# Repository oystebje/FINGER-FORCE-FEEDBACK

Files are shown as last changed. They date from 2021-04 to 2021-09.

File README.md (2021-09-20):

# FINGER-FORCE-FEEDBACK

Repository for project on reality-based modelling of partial meniscectomy.

Repository contains code and CAD models for:
1) Prototype for collecting force-position data from Acufect Upbiter Punch, with ARDUINO MKR Zero based FSR-sensor and potentiometer.
2) Protype for rendering haptic feedback of partial meniscectomy using self-designed hardware, Arduino DUE with SimpleFOC shield, BLDC motor, and AMT 102V encoder.

Prototype for collecting data:


Prototype for haptic rendering:




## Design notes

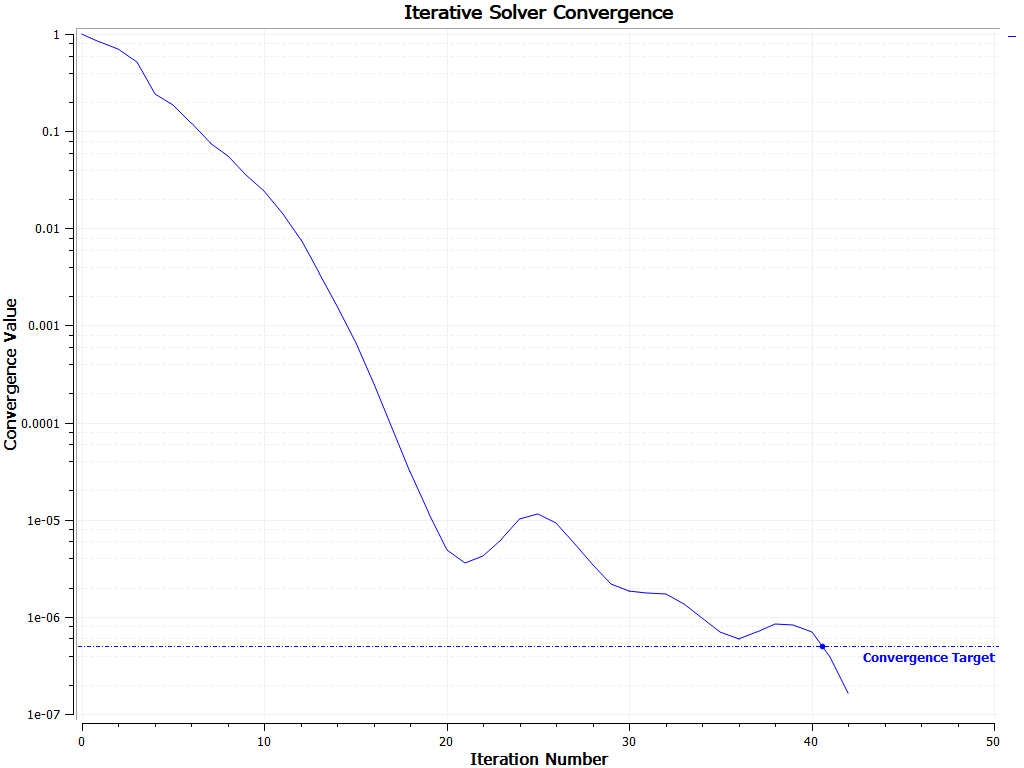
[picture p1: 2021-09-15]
1_Prototype_for_data_collection/CAD/Hand_Held_Devices_Concept/Iterative Solver Convergence.png

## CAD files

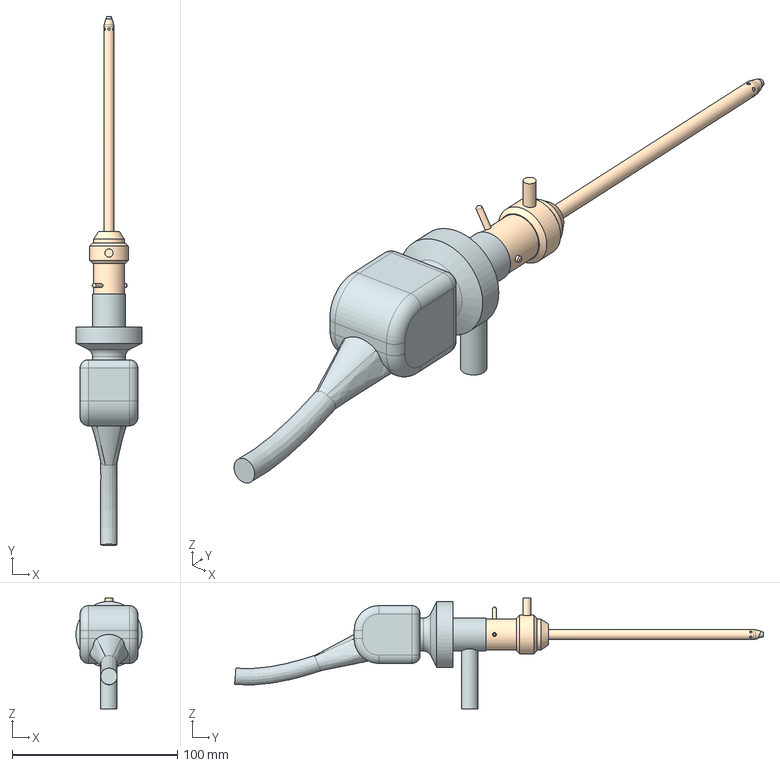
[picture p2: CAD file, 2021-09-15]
1_Prototype_for_data_collection/CAD/Hand_Held_Devices_Concept/STP/SCOPE_ASSEMBLY.stp
40.0 x 320.5 x 67.0 mm
INTRODUCER_SLEEVE
SCOPE_DUMMY

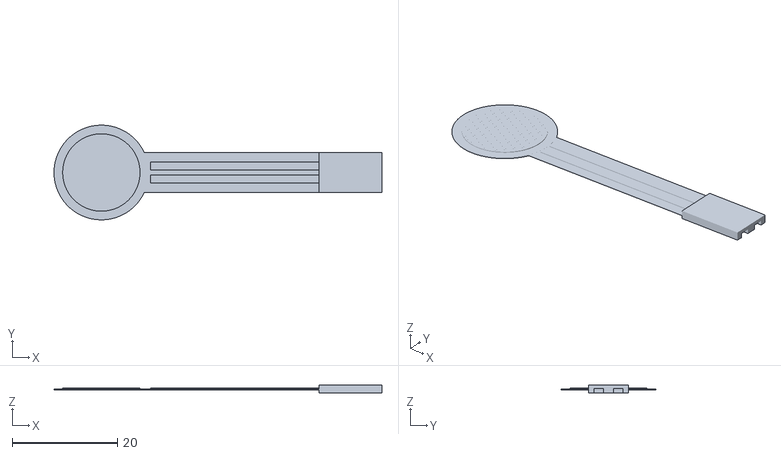
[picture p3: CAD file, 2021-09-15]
1_Prototype_for_data_collection/CAD/3D-print/FSR07CE.stl
62.3 x 18.0 x 1.50

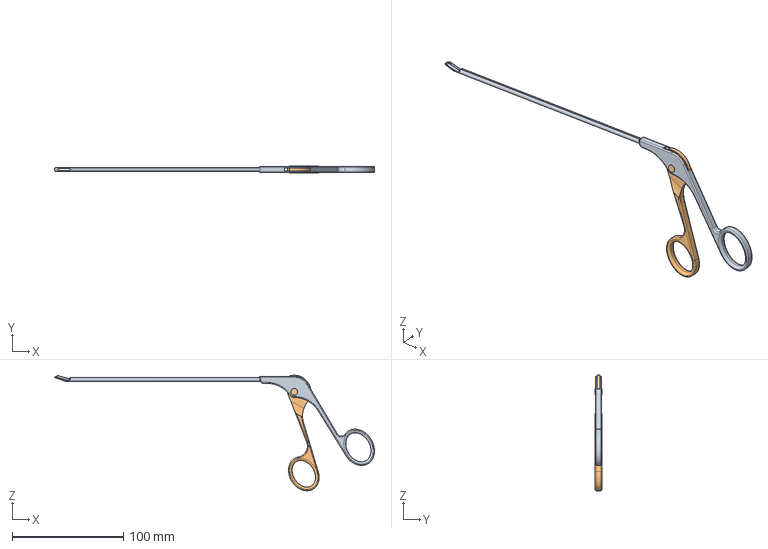
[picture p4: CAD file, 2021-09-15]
1_Prototype_for_data_collection/CAD/Hand_Held_Devices_Concept/STP/ACUFEX_1_5mm_UPBITER_PUNCH_7207735.stp
287.8 x 6.00 x 103.9 mm
ACUFEX_PUNCH_MAIN_BODY
ACUFEX_TRIGGER

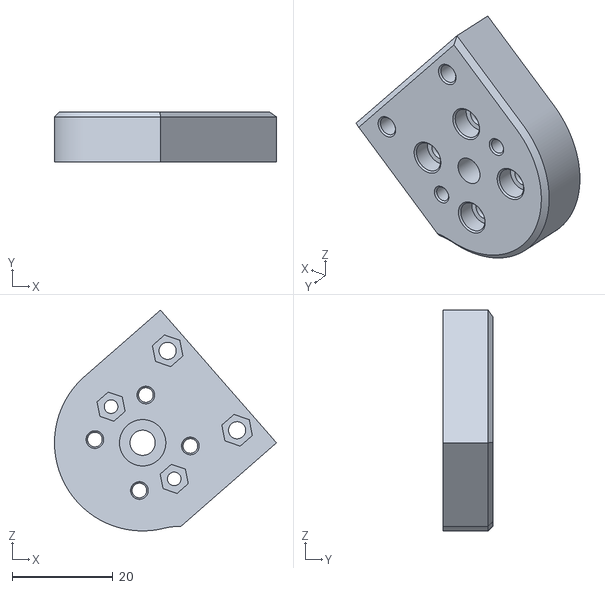
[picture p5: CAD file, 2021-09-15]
2_Prototype_for_haptic_rendering/CAD/3D-PRINT/THUMB_KNOB_REVC_1.stl
44.1 x 10.0 x 43.8

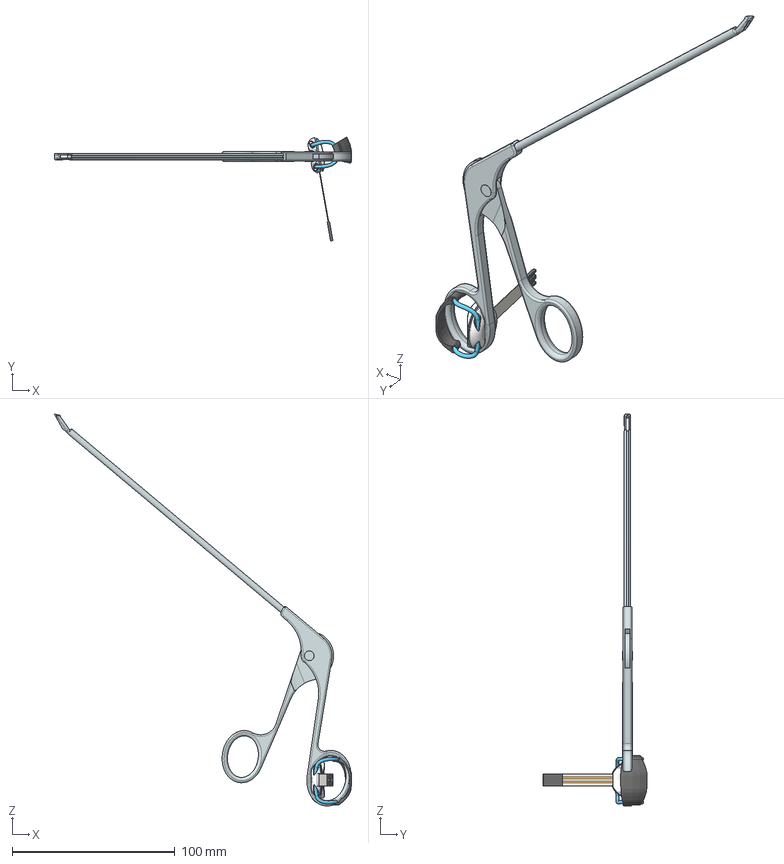
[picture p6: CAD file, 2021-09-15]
1_Prototype_for_data_collection/CAD/Hand_Held_Devices_Concept/STP/FINGER_DEVICE_CONCEPT_1.stp
182.8 x 64.0 x 240.9 mm
FSR07CE
FSR07_thumb_adapter
FSR07_THUMB_ADAPTER_TOP
Rope_attachment
Strap
hand_import
ACUFEX_PUNCH_MAIN_BODY
ACUFEX_TRIGGER

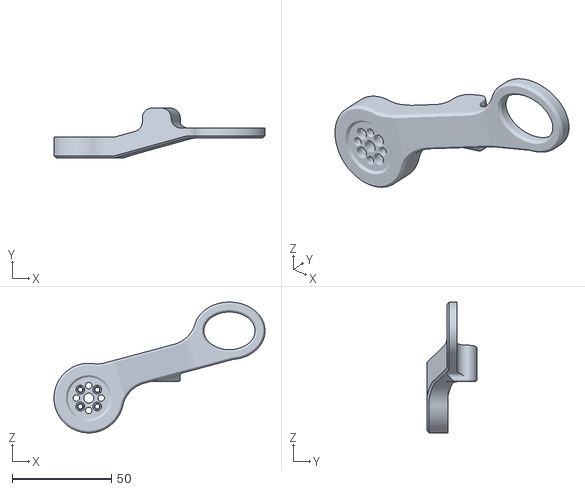
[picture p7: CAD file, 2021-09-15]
2_Prototype_for_haptic_rendering/CAD/3D-PRINT/FINGER_HANDLE_REVD.stl
106.1 x 25.0 x 65.7

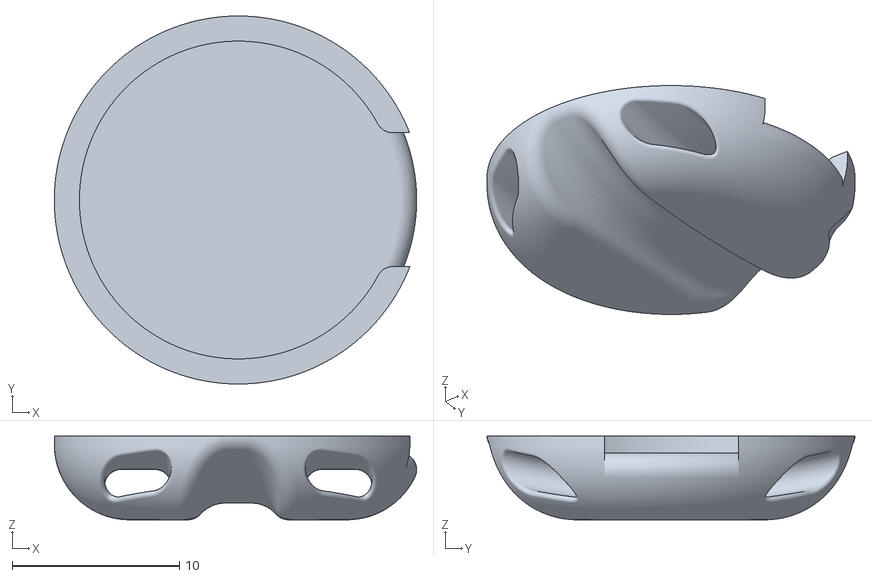
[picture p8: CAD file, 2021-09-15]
1_Prototype_for_data_collection/CAD/3D-print/FSR07_thumb_adapter.stl
21.7 x 22.0 x 5.00

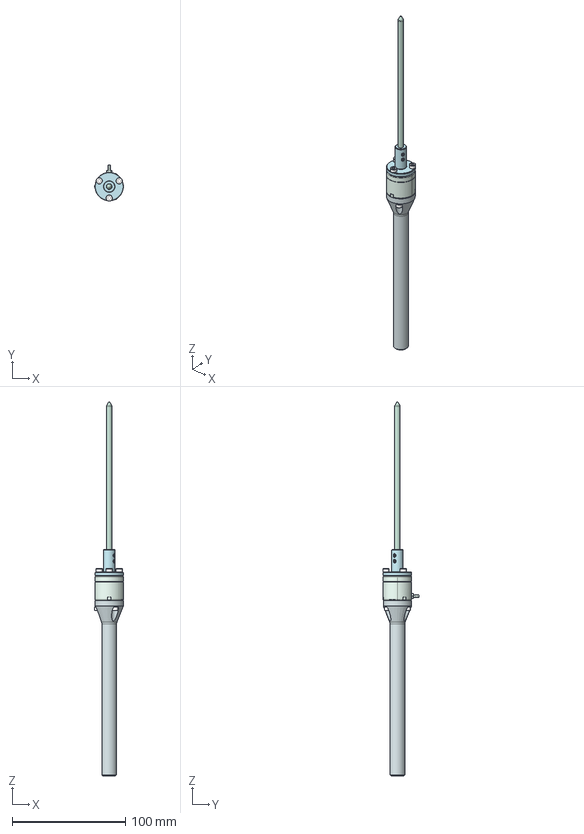
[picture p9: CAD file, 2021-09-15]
1_Prototype_for_data_collection/CAD/Hand_Held_Devices_Concept/STP/Hand_held_concept2_01022021.stp
25.4 x 32.2 x 330.2 mm
ATI-9105-TW-NANO25-R
CONCEPT2_ADAPTER
Dilatator
CONCEPT2_HANDLE
bolt_din912_m3x12 x 6
SET_SCREW_DIN914_M3x4 x 2

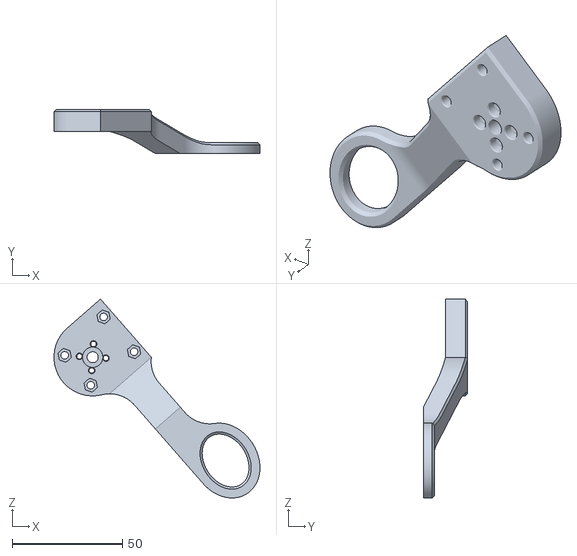
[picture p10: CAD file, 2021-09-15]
2_Prototype_for_haptic_rendering/CAD/3D-PRINT/THUMB_HANDLE.stl
93.3 x 20.0 x 90.0

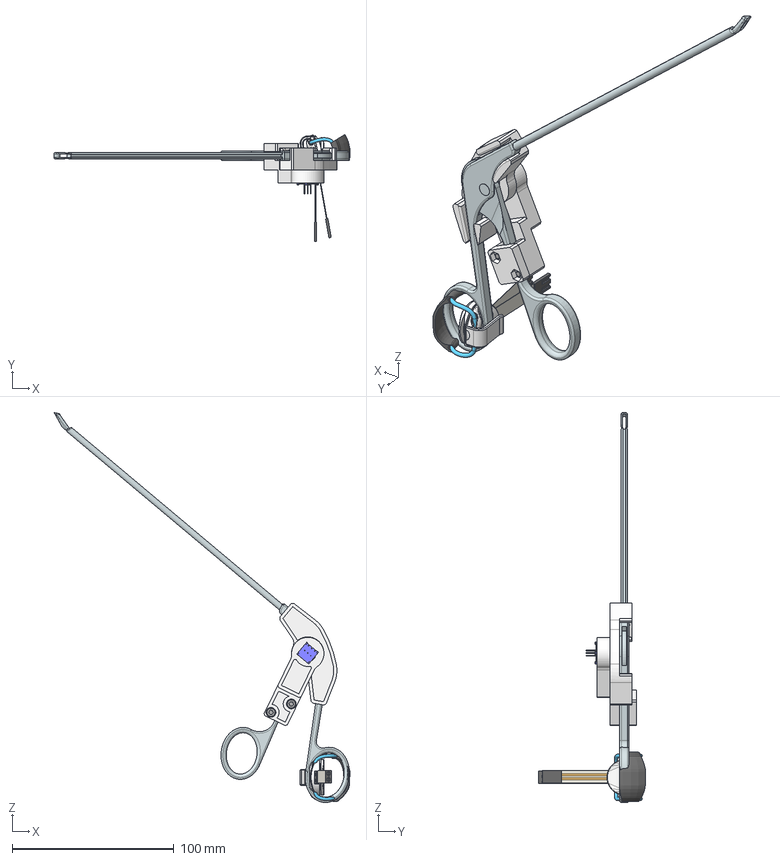
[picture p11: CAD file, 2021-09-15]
1_Prototype_for_data_collection/CAD/Hand_Held_Devices_Concept/STP/FINGER_DEVICE_CONCEPT_1_27052021.stp
182.8 x 66.2 x 240.9 mm
FSR07CE x 2
FSR07_thumb_adapter
FSR07_THUMB_ADAPTER_TOP
Rope_attachment
Strap
hand_import
ACUFEX_PUNCH_MAIN_BODY
ACUFEX_TRIGGER
COM-09806_Potentiometer x 2
POTMETER_FRAME_1
POTMETER_FRAME_2
bolt_din912_m3x12 x 2
POTMETER_FRAME_3
FSR_BASE
FSR_TOP

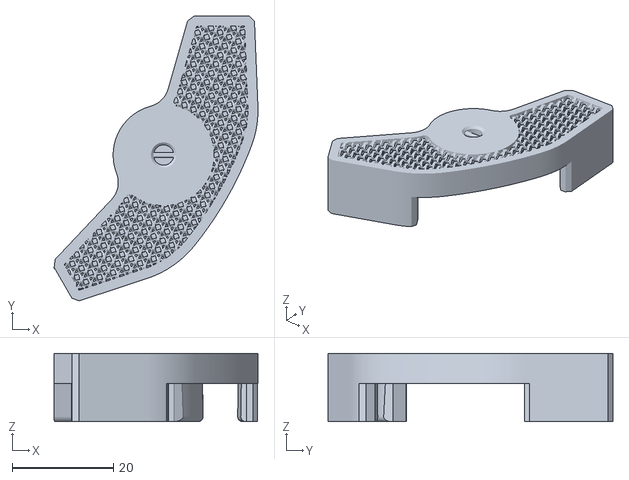
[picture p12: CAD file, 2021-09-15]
1_Prototype_for_data_collection/CAD/3D-print/POTMETER_FRAME_1_RevC.stl
40.4 x 56.4 x 13.5

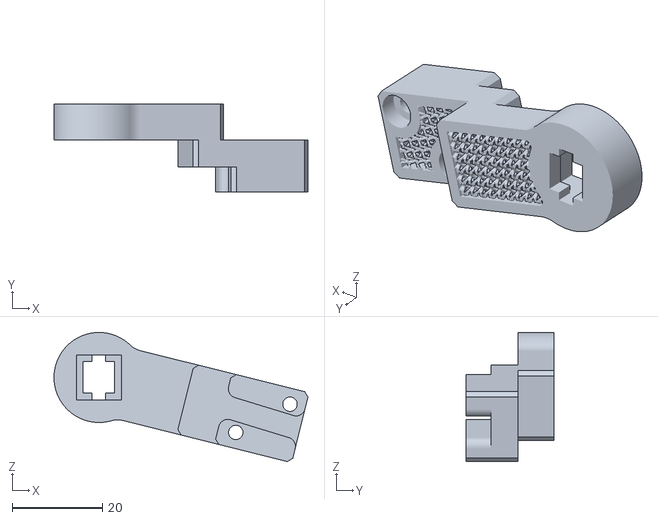
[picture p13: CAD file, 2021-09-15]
1_Prototype_for_data_collection/CAD/3D-print/POTMETER_FRAME_2_RevC.stl
56.4 x 19.5 x 28.7

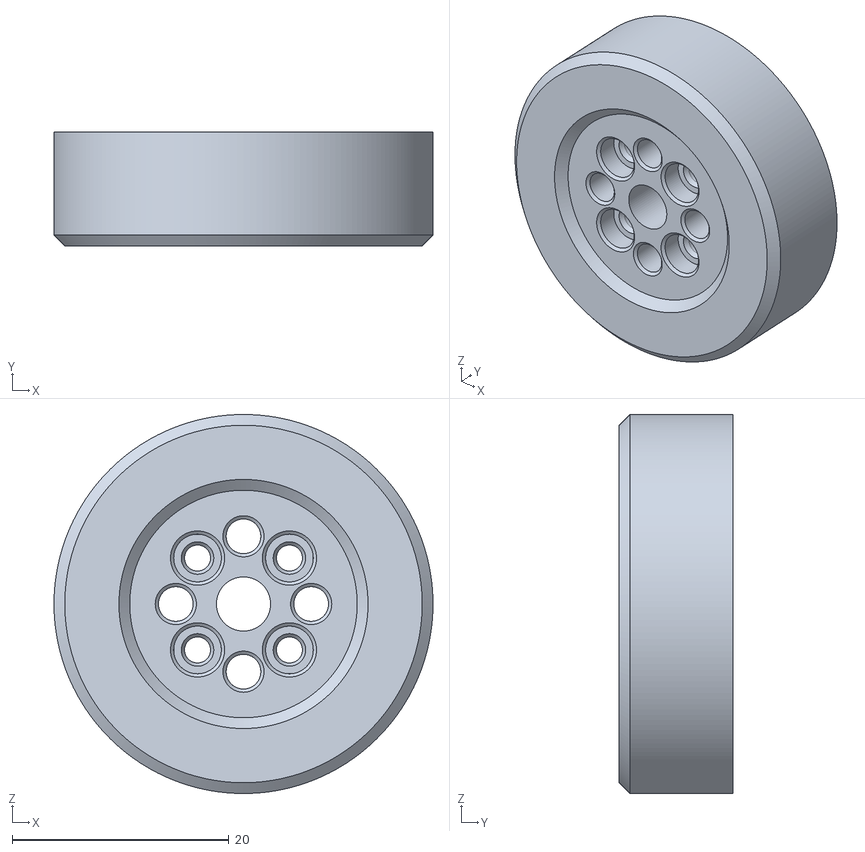
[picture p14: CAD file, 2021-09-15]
2_Prototype_for_haptic_rendering/CAD/3D-PRINT/FINGER_KNOB_REVC_1.stl
35.0 x 10.5 x 35.0

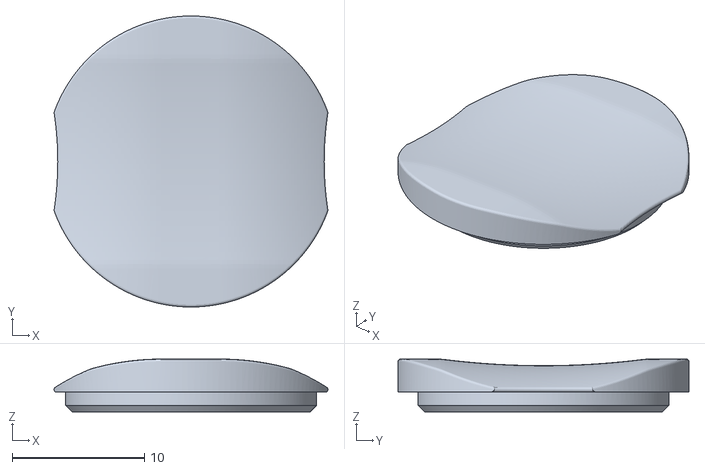
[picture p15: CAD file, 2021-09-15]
1_Prototype_for_data_collection/CAD/3D-print/FSR07_THUMB_ADAPTER_TOP_RevB.stl
20.7 x 22.0 x 4.00

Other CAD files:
1_Prototype_for_data_collection/CAD/3D-print/FSR07_thumb_adapter_RevB.stl
2_Prototype_for_haptic_rendering/CAD/3D-PRINT/CONCEPT2_HANDLE.stl
1_Prototype_for_data_collection/CAD/3D-print/POTMETER_FRAME_3.stl
2_Prototype_for_haptic_rendering/CAD/3D-PRINT/TOOL_ADAPTER.stl
1_Prototype_for_data_collection/CAD/3D-print/FSR_BASE_RevA.stl
1_Prototype_for_data_collection/CAD/3D-print/FSR_TOP.stl
1_Prototype_for_data_collection/CAD/3D-print/POTMETER_FRAME_1.stl
1_Prototype_for_data_collection/CAD/3D-print/POTMETER_FRAME_1_RevB.stl
1_Prototype_for_data_collection/CAD/3D-print/POTMETER_FRAME_2.stl
1_Prototype_for_data_collection/CAD/3D-print/POTMETER_FRAME_2_RevB.stl
1_Prototype_for_data_collection/CAD/BACKUPS/Hand_Held_Devices_Concept/ACUFEX_1_5mm_UPBITER_PUNCH_7207735.prt
1_Prototype_for_data_collection/CAD/BACKUPS/Hand_Held_Devices_Concept/ACUFEX_PUNCH_MAIN_BODY.prt
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

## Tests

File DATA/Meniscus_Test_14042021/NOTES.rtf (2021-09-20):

NOTES:

PART I: Samples with tape covering FSR sensor. Idea was to get better force distribution over FSR, but ended up biasing measures (force not being zero unloaded)

PART II: Tape was removed. Zero force on zero load, but pay attention to force behavior.

No cut through for the following tests:
- Pattellar ligament fast&slow
- Skin knee lateral fast&slow
- Muscle posterior

Mostly cut through for meniscus tests. Perhaps less frequent for later ones (PART II).

Some hysteresis from previous cutting on later tests.

MUSCLE POSTERIOR:
Difficult to tell whether cut through or not. Generally very little resistance (stiffness).

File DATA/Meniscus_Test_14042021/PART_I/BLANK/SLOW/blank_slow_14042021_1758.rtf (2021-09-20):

Please move the lever to the outermost position and hold for 5 seconds
Outermost position recorded
Please move the lever to the innermost position and hold for 5 seconds
Innermost position recorded
Potentiometer calibration completed
FSR reading, FSR Force [N], angle [deg], time [ms]
1 0.73 486.00 9.23 30003.00
1 0.73 486.00 9.23 30005.00
0 0.00 486.00 9.23 30008.00
0 0.00 485.00 8.97 30010.00
1 0.73 486.00 9.23 30013.00
1 0.73 485.00 8.97 30016.00
0 0.00 486.00 9.23 30018.00
1 0.73 487.00 9.48 30021.00
0 0.00 486.00 9.23 30024.00
1 0.73 486.00 9.23 30026.00
1 0.73 486.00 9.23 30029.00
0 0.00 486.00 9.23 30031.00
1 0.73 485.00 8.97 30034.00
1 0.73 487.00 9.48 30037.00
1 0.73 486.00 9.23 30039.00
0 0.00 486.00 9.23 30042.00
0 0.00 485.00 8.97 30045.00
0 0.00 486.00 9.23 30047.00
0 0.00 487.00 9.48 30050.00
1 0.73 486.00 9.23 30052.00
0 0.00 486.00 9.23 30055.00
0 0.00 487.00 9.48 30058.00
1 0.73 486.00 9.23 30060.00
1 0.73 486.00 9.23 30063.00
1 0.73 486.00 9.23 30066.00
1 0.73 486.00 9.23 30068.00
1 0.73 487.00 9.48 30071.00
0 0.00 485.00 8.97 30073.00
1 0.73 486.00 9.23 30076.00
0 0.00 486.00 9.23 30079.00
1 0.73 485.00 8.97 30081.00
1 0.73 486.00 9.23 30084.00
1 0.73 486.00 9.23 30087.00
0 0.00 486.00 9.23 30089.00
0 0.00 486.00 9.23 30092.00
0 0.00 485.00 8.97 30094.00
1 0.73 486.00 9.23 30097.00
1 0.73 486.00 9.23 30100.00
1 0.73 485.00 8.97 30102.00
1 0.73 485.00 8.97 30105.00
1 0.73 485.00 8.97 30107.00
1 0.73 486.00 9.23 30110.00
1 0.73 486.00 9.23 30113.00
1 0.73 486.00 9.23 30115.00
0 0.00 486.00 9.23 30118.00
0 0.00 486.00 9.23 30120.00
1 0.73 486.00 9.23 30123.00
1 0.73 486.00 9.23 30126.00
2 1.45 486.00 9.23 30129.00
0 0.00 485.00 8.97 30131.00
2 1.45 487.00 9.48 30134.00
1 0.73 486.00 9.23 30137.00
0 0.00 486.00 9.23 30139.00
1 0.73 485.00 8.97 30142.00
2 1.45 485.00 8.97 30145.00
1 0.73 486.00 9.23 30148.00
0 0.00 486.00 9.23 30150.00
1 0.73 486.00 9.23 30153.00
1 0.73 486.00 9.23 30155.00
1 0.73 486.00 9.23 30158.00
0 0.00 485.00 8.97 30161.00
1 0.73 485.00 8.97 30163.00
1 0.73 485.00 8.97 30166.00
1 0.73 486.00 9.23 30169.00
0 0.00 486.00 9.23 30171.00
0 0.00 486.00 9.23 30174.00
1 0.73 486.00 9.23 30176.00
0 0.00 487.00 9.48 30179.00
1 0.73 486.00 9.23 30182.00
1 0.73 487.00 9.48 30184.00
1 0.73 488.00 9.74 30187.00
1 0.73 487.00 9.48 30189.00
0 0.00 486.00 9.23 30192.00
1 0.73 487.00 9.48 30195.00
0 0.00 486.00 9.23 30197.00
2 1.45 485.00 8.97 30200.00
1 0.73 486.00 9.23 30203.00
0 0.00 487.00 9.48 30206.00
1 0.73 486.00 9.23 30208.00
1 0.73 487.00 9.48 30211.00
0 0.00 486.00 9.23 30213.00
1 0.73 486.00 9.23 30216.00
1 0.73 486.00 9.23 30219.00
1 0.73 486.00 9.23 30221.00
0 0.00 486.00 9.23 30224.00
0 0.00 487.00 9.48 30226.00
1 0.73 485.00 8.97 30229.00
0 0.00 486.00 9.23 30232.00
0 0.00 485.00 8.97 30234.00
0 0.00 486.00 9.23 30237.00
1 0.73 485.00 8.97 30239.00
1 0.73 486.00 9.23 30242.00
1 0.73 486.00 9.23 30245.00
1 0.73 486.00 9.23 30247.00
0 0.00 485.00 8.97 30250.00
2 1.45 486.00 9.23 30253.00
1 0.73 486.00 9.23 30256.00
1 0.73 485.00 8.97 30258.00
1 0.73 486.00 9.23 30261.00
1 0.73 485.00 8.97 30263.00
0 0.00 486.00 9.23 30266.00
1 0.73 486.00 9.23 30269.00
0 0.00 486.00 9.23 30271.00
0 0.00 485.00 8.97 30274.00
0 0.00 485.00 8.97 30276.00
1 0.73 485.00 8.97 30279.00
0 0.00 486.00 9.23 30282.00
1 0.73 486.00 9.23 30284.00
0 0.00 485.00 8.97 30287.00
0 0.00 487.00 9.48 30290.00
0 0.00 486.00 9.23 30292.00
1 0.73 486.00 9.23 30295.00
1 0.73 486.00 9.23 30298.00
0 0.00 486.00 9.23 30300.00
1 0.73 485.00 8.97 30303.00
2 1.45 486.00 9.23 30306.00
0 0.00 484.00 8.71 30308.00
0 0.00 486.00 9.23 30311.00
1 0.73 484.00 8.71 30314.00
0 0.00 484.00 8.71 30316.00
0 0.00 486.00 9.23 30319.00
1 0.73 486.00 9.23 30321.00
1 0.73 486.00 9.23 30324.00
0 0.00 485.00 8.97 30327.00
1 0.73 487.00 9.48 30329.00
1 0.73 487.00 9.48 30332.00
1 0.73 486.00 9.23 30334.00
1 0.73 486.00 9.23 30337.00
0 0.00 487.00 9.48 30340.00
0 0.00 486.00 9.23 30342.00
0 0.00 486.00 9.23 30345.00
1 0.73 486.00 9.23 30347.00
0 0.00 486.00 9.23 30350.00
0 0.00 486.00 9.23 30353.00
1 0.73 486.00 9.23 30355.00
0 0.00 486.00 9.23 30358.00
0 0.00 486.00 9.23 30360.00
0 0.00 487.00 9.48 30363.00
1 0.73 485.00 8.97 30366.00
1 0.73 486.00 9.23 30368.00
0 0.00 486.00 9.23 30371.00
1 0.73 486.00 9.23 30374.00
1 0.73 486.00 9.23 30376.00
1 0.73 486.00 9.23 30379.00
1 0.73 486.00 9.23 30381.00
0 0.00 486.00 9.23 30384.00
0 0.00 485.00 8.97 30387.00
5 3.62 486.00 9.23 30390.00
5 3.62 485.00 8.97 30393.00
7 5.07 485.00 8.97 30396.00
7 5.07 485.00 8.97 30399.00
15 10.83 486.00 9.23 30403.00
15 10.83 486.00 9.23 30406.00
16 11.54 487.00 9.48 30409.00
21 15.12 485.00 8.97 30412.00
20 14.40 486.00 9.23 30415.00
22 15.83 486.00 9.23 30419.00
22 15.83 485.00 8.97 30422.00
27 19.39 486.00 9.23 30425.00
32 22.94 485.00 8.97 30428.00
31 22.23 485.00 8.97 30431.00
32 22.94 486.00 9.23 30434.00
32 22.94 485.00 8.97 30437.00
33 23.65 486.00 9.23 30441.00
33 23.65 487.00 9.48 30444.00
32 22.94 486.00 9.23 30447.00
33 23.65 485.00 8.97 30450.00
32 22.94 486.00 9.23 30453.00
34 24.35 486.00 9.23 30456.00
31 22.23 485.00 8.97 30459.00
32 22.94 486.00 9.23 30462.00
33 23.65 486.00 9.23 30466.00
32 22.94 484.00 8.71 30469.00
35 25.06 484.00 8.71 30472.00
38 27.18 486.00 9.23 30475.00
36 25.76 485.00 8.97 30478.00
45 32.09 485.00 8.97 30482.00
44 31.39 485.00 8.97 30485.00
45 32.09 485.00 8.97 30488.00
47 33.50 486.00 9.23 30491.00
46 32.80 487.00 9.48 30495.00
46 32.80 486.00 9.23 30498.00
45 32.09 486.00 9.23 30501.00
45 32.09 485.00 8.97 30504.00
48 34.19 485.00 8.97 30507.00
48 34.19 486.00 9.23 30511.00
49 34.89 485.00 8.97 30514.00
48 34.19 485.00 8.97 30517.00
47 33.50 485.00 8.97 30520.00
48 34.19 485.00 8.97 30523.00
48 34.19 486.00 9.23 30526.00
49 34.89 487.00 9.48 30530.00
48 34.19 485.00 8.97 30533.00
50 35.59 485.00 8.97 30536.00
50 35.59 487.00 9.48 30539.00
49 34.89 486.00 9.23 30542.00
50 35.59 487.00 9.48 30546.00
49 34.89 486.00 9.23 30549.00
47 33.50 484.00 8.71 30552.00
46 32.80 486.00 9.23 30555.00
46 32.80 485.00 8.97 30558.00
46 32.80 486.00 9.23 30562.00
46 32.80 486.00 9.23 30565.00
44 31.39 485.00 8.97 30568.00
39 27.88 485.00 8.97 30571.00
34 24.35 486.00 9.23 30575.00
28 20.10 485.00 8.97 30578.00
30 21.52 484.00 8.71 30581.00
28 20.10 485.00 8.97 30585.00
32 22.94 486.00 9.23 30588.00
33 23.65 485.00 8.97 30591.00
28 20.10 485.00 8.97 30594.00
27 19.39 485.00 8.97 30597.00
28 20.10 485.00 8.97 30601.00
25 17.97 486.00 9.23 30604.00
28 20.10 487.00 9.48 30607.00
28 20.10 486.00 9.23 30610.00
26 18.68 485.00 8.97 30614.00
29 20.81 485.00 8.97 30617.00
29 20.81 485.00 8.97 30620.00
32 22.94 486.00 9.23 30623.00
32 22.94 486.00 9.23 30626.00
29 20.81 485.00 8.97 30629.00
32 22.94 484.00 8.71 30632.00
30 21.52 486.00 9.23 30635.00
29 20.81 485.00 8.97 30639.00
29 20.81 485.00 8.97 30642.00
27 19.39 485.00 8.97 30645.00
28 20.10 486.00 9.23 30648.00
26 18.68 485.00 8.97 30652.00
30 21.52 486.00 9.23 30655.00
21 15.12 485.00 8.97 30658.00
25 17.97 484.00 8.71 30661.00
25 17.97 486.00 9.23 30665.00
28 20.10 485.00 8.97 30668.00
30 21.52 486.00 9.23 30671.00
31 22.23 486.00 9.23 30674.00
35 25.06 486.00 9.23 30678.00
32 22.94 485.00 8.97 30681.00
32 22.94 486.00 9.23 30684.00
29 20.81 485.00 8.97 30687.00
29 20.81 484.00 8.71 30690.00
27 19.39 485.00 8.97 30693.00
24 17.26 486.00 9.23 30697.00
23 16.55 485.00 8.97 30700.00
21 15.12 486.00 9.23 30703.00
17 12.26 484.00 8.71 30706.00
17 12.26 486.00 9.23 30710.00
21 15.12 486.00 9.23 30713.00
19 13.69 484.00 8.71 30716.00
20 14.40 485.00 8.97 30719.00
23 16.55 486.00 9.23 30723.00
22 15.83 485.00 8.97 30726.00
26 18.68 487.00 9.48 30729.00
26 18.68 485.00 8.97 30732.00
27 19.39 485.00 8.97 30735.00
27 19.39 486.00 9.23 30739.00
24 17.26 485.00 8.97 30742.00
26 18.68 486.00 9.23 30745.00
23 16.55 486.00 9.23 30748.00
23 16.55 485.00 8.97 30752.00
23 16.55 485.00 8.97 30755.00
23 16.55 486.00 9.23 30758.00
22 15.83 486.00 9.23 30761.00
22 15.83 486.00 9.23 30765.00
29 20.81 486.00 9.23 30768.00
27 19.39 484.00 8.71 30771.00
24 17.26 485.00 8.97 30774.00
23 16.55 484.00 8.71 30777.00
25 17.97 485.00 8.97 30781.00
25 17.97 486.00 9.23 30784.00
34 24.35 486.00 9.23 30787.00
32 22.94 486.00 9.23 30790.00
26 18.68 485.00 8.97 30793.00
41 29.29 485.00 8.97 30797.00
45 32.09 486.00 9.23 30800.00
49 34.89 484.00 8.71 30803.00
50 35.59 486.00 9.23 30806.00
49 34.89 485.00 8.97 30810.00
46 32.80 486.00 9.23 30813.00
47 33.50 487.00 9.48 30816.00
50 35.59 485.00 8.97 30819.00
49 34.89 484.00 8.71 30822.00
45 32.09 487.00 9.48 30826.00
39 27.88 486.00 9.23 30829.00
51 36.29 487.00 9.48 30832.00
51 36.29 487.00 9.48 30835.00
47 33.50 486.00 9.23 30839.00
43 30.69 487.00 9.48 30842.00
50 35.59 486.00 9.23 30845.00
43 30.69 486.00 9.23 30848.00
42 29.99 485.00 8.97 30852.00
42 29.99 486.00 9.23 30855.00
46 32.80 487.00 9.48 30858.00
48 34.19 486.00 9.23 30861.00
47 33.50 487.00 9.48 30865.00
46 32.80 486.00 9.23 30868.00
56 39.77 487.00 9.48 30871.00
58 41.16 486.00 9.23 30874.00
59 41.86 487.00 9.48 30878.00
58 41.16 487.00 9.48 30881.00
58 41.16 487.00 9.48 30884.00
57 40.47 488.00 9.74 30887.00
57 40.47 488.00 9.74 30890.00
57 40.47 487.00 9.48 30894.00
57 40.47 487.00 9.48 30897.00
57 40.47 488.00 9.74 30900.00
59 41.86 487.00 9.48 30903.00
58 41.16 487.00 9.48 30907.00
59 41.86 488.00 9.74 30910.00
59 41.86 488.00 9.74 30913.00
59 41.86 488.00 9.74 30916.00
59 41.86 488.00 9.74 30920.00
58 41.16 488.00 9.74 30923.00
58 41.16 488.00 9.74 30926.00
60 42.55 488.00 9.74 30929.00
61 43.24 488.00 9.74 30932.00
61 43.24 489.00 10.00 30936.00
62 43.94 490.00 10.25 30939.00
63 44.63 490.00 10.25 30942.00
65 46.01 490.00 10.25 30945.00
65 46.01 490.00 10.25 30948.00
66 46.70 490.00 10.25 30952.00
62 43.94 491.00 10.51 30955.00
62 43.94 488.00 9.74 30958.00
74 52.21 490.00 10.25 30961.00
71 50.15 491.00 10.51 30965.00
66 46.70 491.00 10.51 30968.00
60 42.55 491.00 10.51 30971.00
7 5.07 491.00 10.51 30974.00
1 0.73 491.00 10.51 30977.00
1 0.73 491.00 10.51 30979.00
3 2.18 490.00 10.25 30983.00
2 1.45 491.00 10.51 30985.00
2 1.45 491.00 10.51 30988.00
3 2.18 491.00 10.51 30992.00
2 1.45 491.00 10.51 30995.00
2 1.45 490.00 10.25 30997.00
2 1.45 491.00 10.51 31000.00
2 1.45 491.00 10.51 31003.00
4 2.90 492.00 10.76 31006.00
4 2.90 491.00 10.51 31009.00
3 2.18 491.00 10.51 31013.00
3 2.18 491.00 10.51 31016.00
4 2.90 492.00 10.76 31019.00
4 2.90 490.00 10.25 31022.00
4 2.90 491.00 10.51 31025.00
3 2.18 490.00 10.25 31028.00
3 2.18 490.00 10.25 31031.00
6 4.35 491.00 10.51 31034.00
4 2.90 491.00 10.51 31037.00
4 2.90 492.00 10.76 31040.00
4 2.90 490.00 10.25 31043.00
3 2.18 491.00 10.51 31046.00
3 2.18 491.00 10.51 31049.00
3 2.18 492.00 10.76 31052.00
3 2.18 491.00 10.51 31055.00
3 2.18 492.00 10.76 31058.00
4 2.90 491.00 10.51 31061.00
3 2.18 491.00 10.51 31064.00
2 1.45 492.00 10.76 31067.00
3 2.18 490.00 10.25 31070.00
2 1.45 491.00 10.51 31073.00
2 1.45 490.00 10.25 31076.00
2 1.45 491.00 10.51 31079.00
3 2.18 491.00 10.51 31082.00
2 1.45 492.00 10.76 31085.00
2 1.45 490.00 10.25 31088.00
1 0.73 491.00 10.51 31091.00
1 0.73 492.00 10.76 31093.00
1 0.73 491.00 10.51 31096.00
1 0.73 491.00 10.51 31099.00
1 0.73 491.00 10.51 31101.00
2 1.45 491.00 10.51 31104.00
2 1.45 492.00 10.76 31107.00
2 1.45 492.00 10.76 31110.00
2 1.45 490.00 10.25 31113.00
0 0.00 491.00 10.51 31116.00
1 0.73 492.00 10.76 31118.00
1 0.73 492.00 10.76 31121.00
1 0.73 492.00 10.76 31124.00
0 0.00 492.00 10.76 31126.00
2 1.45 491.00 10.51 31129.00
2 1.45 492.00 10.76 31132.00
0 0.00 490.00 10.25 31135.00
0 0.00 491.00 10.51 31137.00
1 0.73 490.00 10.25 31140.00
1 0.73 491.00 10.51 31142.00
1 0.73 491.00 10.51 31145.00
0 0.00 492.00 10.76 31148.00
0 0.00 492.00 10.76 31150.00
0 0.00 491.00 10.51 31153.00
0 0.00 491.00 10.51 31155.00
1 0.73 493.00 11.02 31158.00
2 1.45 491.00 10.51 31161.00
0 0.00 491.00 10.51 31164.00
2 1.45 492.00 10.76 31167.00
0 0.00 491.00 10.51 31169.00
2 1.45 491.00 10.51 31172.00
1 0.73 492.00 10.76 31175.00
2 1.45 491.00 10.51 31178.00
2 1.45 492.00 10.76 31181.00
0 0.00 491.00 10.51 31183.00
1 0.73 491.00 10.51 31186.00
2 1.45 492.00 10.76 31189.00
1 0.73 491.00 10.51 31191.00
0 0.00 492.00 10.76 31194.00
1 0.73 491.00 10.51 31197.00
0 0.00 492.00 10.76 31199.00
0 0.00 491.00 10.51 31202.00
1 0.73 491.00 10.51 31204.00
1 0.73 491.00 10.51 31207.00
1 0.73 492.00 10.76 31210.00
1 0.73 493.00 11.02 31212.00
1 0.73 491.00 10.51 31215.00
1 0.73 491.00 10.51 31217.00
1 0.73 492.00 10.76 31220.00
2 1.45 491.00 10.51 31223.00
0 0.00 492.00 10.76 31226.00
0 0.00 492.00 10.76 31228.00
1 0.73 491.00 10.51 31231.00
1 0.73 492.00 10.76 31233.00
0 0.00 491.00 10.51 31236.00
1 0.73 491.00 10.51 31239.00
2 1.45 492.00 10.76 31242.00
0 0.00 491.00 10.51 31244.00
1 0.73 491.00 10.51 31247.00
1 0.73 492.00 10.76 31249.00
1 0.73 490.00 10.25 31252.00
1 0.73 491.00 10.51 31255.00
0 0.00 491.00 10.51 31257.00
0 0.00 491.00 10.51 31260.00
1 0.73 492.00 10.76 31262.00
1 0.73 491.00 10.51 31265.00
1 0.73 491.00 10.51 31268.00
1 0.73 492.00 10.76 31270.00
1 0.73 491.00 10.51 31273.00
1 0.73 491.00 10.51 31275.00
0 0.00 492.00 10.76 31278.00
1 0.73 492.00 10.76 31281.00
0 0.00 491.00 10.51 31283.00
2 1.45 491.00 10.51 31286.00
0 0.00 492.00 10.76 31289.00
1 0.73 492.00 10.76 31291.00
1 0.73 491.00 10.51 31294.00
1 0.73 491.00 10.51 31297.00
0 0.00 491.00 10.51 31299.00
0 0.00 491.00 10.51 31302.00
1 0.73 492.00 10.76 31304.00
1 0.73 491.00 10.51 31307.00
1 0.73 491.00 10.51 31310.00
1 0.73 492.00 10.76 31312.00
0 0.00 492.00 10.76 31315.00
0 0.00 491.00 10.51 31317.00
0 0.00 492.00 10.76 31320.00
1 0.73 491.00 10.51 31323.00
1 0.73 491.00 10.51 31325.00
1 0.73 491.00 10.51 31328.00
0 0.00 492.00 10.76 31330.00
1 0.73 492.00 10.76 31333.00
0 0.00 491.00 10.51 31336.00
1 0.73 491.00 10.51 31338.00
0 0.00 492.00 10.76 31341.00
1 0.73 492.00 10.76 31343.00
1 0.73 491.00 10.51 31346.00
1 0.73 492.00 10.76 31349.00
1 0.73 490.00 10.25 31351.00
0 0.00 490.00 10.25 31354.00
0 0.00 491.00 10.51 31356.00
1 0.73 492.00 10.76 31359.00
0 0.00 491.00 10.51 31362.00
1 0.73 492.00 10.76 31364.00
1 0.73 490.00 10.25 31367.00
1 0.73 492.00 10.76 31369.00
2 1.45 492.00 10.76 31372.00
1 0.73 491.00 10.51 31375.00
0 0.00 490.00 10.25 31378.00
0 0.00 491.00 10.51 31380.00
0 0.00 492.00 10.76 31383.00
0 0.00 492.00 10.76 31385.00
1 0.73 491.00 10.51 31388.00
1 0.73 491.00 10.51 31391.00
1 0.73 491.00 10.51 31393.00
1 0.73 491.00 10.51 31396.00
0 0.00 489.00 10.00 31399.00
1 0.73 492.00 10.76 31401.00
1 0.73 491.00 10.51 31404.00
1 0.73 491.00 10.51 31407.00
0 0.00 491.00 10.51 31409.00
1 0.73 490.00 10.25 31412.00
0 0.00 489.00 10.00 31414.00
0 0.00 491.00 10.51 31417.00
1 0.73 489.00 10.00 31420.00
0 0.00 491.00 10.51 31422.00
1 0.73 490.00 10.25 31425.00
1 0.73 490.00 10.25 31428.00
0 0.00 490.00 10.25 31430.00
1 0.73 489.00 10.00 31433.00
1 0.73 490.00 10.25 31435.00
1 0.73 489.00 10.00 31438.00
0 0.00 489.00 10.00 31441.00
1 0.73 489.00 10.00 31443.00
1 0.73 489.00 10.00 31446.00
0 0.00 489.00 10.00 31448.00
2 1.45 490.00 10.25 31451.00
0 0.00 488.00 9.74 31454.00
1 0.73 489.00 10.00 31457.00
1 0.73 489.00 10.00 31459.00
1 0.73 489.00 10.00 31462.00
1 0.73 489.00 10.00 31464.00
1 0.73 489.00 10.00 31467.00
1 0.73 489.00 10.00 31470.00
1 0.73 488.00 9.74 31472.00
1 0.73 488.00 9.74 31475.00
1 0.73 488.00 9.74 31477.00
0 0.00 488.00 9.74 31480.00
0 0.00 488.00 9.74 31483.00
0 0.00 488.00 9.74 31485.00
0 0.00 488.00 9.74 31488.00
1 0.73 488.00 9.74 31490.00
1 0.73 487.00 9.48 31493.00
2 1.45 486.00 9.23 31496.00
0 0.00 487.00 9.48 31499.00
1 0.73 486.00 9.23 31501.00
1 0.73 486.00 9.23 31504.00
1 0.73 486.00 9.23 31506.00
0 0.00 486.00 9.23 31509.00
1 0.73 486.00 9.23 31512.00
1 0.73 487.00 9.48 31514.00
1 0.73 485.00 8.97 31517.00
1 0.73 484.00 8.71 31520.00
0 0.00 486.00 9.23 31522.00
1 0.73 484.00 8.71 31525.00
1 0.73 486.00 9.23 31527.00
1 0.73 486.00 9.23 31530.00
1 0.73 485.00 8.97 31533.00
0 0.00 484.00 8.71 31535.00
0 0.00 484.00 8.71 31538.00
1 0.73 483.00 8.46 31540.00
1 0.73 484.00 8.71 31543.00
0 0.00 484.00 8.71 31545.00
0 0.00 483.00 8.46 31548.00
1 0.73 483.00 8.46 31551.00
0 0.00 483.00 8.46 31553.00
0 0.00 482.00 8.20 31556.00
1 0.73 483.00 8.46 31558.00
1 0.73 482.00 8.20 31561.00
0 0.00 481.00 7.94 31564.00
0 0.00 480.00 7.69 31566.00
0 0.00 481.00 7.94 31569.00
1 0.73 480.00 7.69 31572.00
1 0.73 479.00 7.43 31574.00
2 1.45 480.00 7.69 31577.00
1 0.73 480.00 7.69 31580.00
1 0.73 479.00 7.43 31582.00
1 0.73 478.00 7.17 31585.00
1 0.73 479.00 7.43 31588.00
1 0.73 479.00 7.43 31590.00
0 0.00 477.00 6.92 31593.00
1 0.73 478.00 7.17 31596.00
0 0.00 477.00 6.92 31598.00
0 0.00 477.00 6.92 31601.00
1 0.73 477.00 6.92 31603.00
0 0.00 477.00 6.92 31606.00
0 0.00 477.00 6.92 31608.00
1 0.73 475.00 6.41 31611.00
0 0.00 475.00 6.41 31614.00
2 1.45 475.00 6.41 31617.00
2 1.45 475.00 6.41 31620.00
1 0.73 475.00 6.41 31622.00
0 0.00 473.00 5.89 31625.00
1 0.73 474.00 6.15 31627.00
1 0.73 474.00 6.15 31630.00
1 0.73 473.00 5.89 31633.00
0 0.00 474.00 6.15 31635.00
1 0.73 473.00 5.89 31638.00
1 0.73 474.00 6.15 31640.00
2 1.45 474.00 6.15 31643.00
1 0.73 474.00 6.15 31646.00
0 0.00 473.00 5.89 31649.00
1 0.73 473.00 5.89 31651.00
1 0.73 473.00 5.89 31654.00
0 0.00 473.00 5.89 31657.00
1 0.73 472.00 5.64 31659.00
2 1.45 471.00 5.38 31662.00
1 0.73 471.00 5.38 31665.00
1 0.73 471.00 5.38 31668.00
0 0.00 471.00 5.38 31670.00
1 0.73 470.00 5.12 31673.00
1 0.73 470.00 5.12 31675.00
1 0.73 468.00 4.61 31678.00
1 0.73 468.00 4.61 31681.00
1 0.73 469.00 4.87 31683.00
1 0.73 468.00 4.61 31686.00
1 0.73 468.00 4.61 31688.00
0 0.00 466.00 4.10 31691.00
0 0.00 467.00 4.35 31694.00
1 0.73 466.00 4.10 31696.00
2 1.45 467.00 4.35 31699.00
1 0.73 467.00 4.35 31702.00
1 0.73 467.00 4.35 31704.00
1 0.73 467.00 4.35 31707.00
0 0.00 466.00 4.10 31710.00
1 0.73 467.00 4.35 31712.00
1 0.73 466.00 4.10 31715.00
0 0.00 465.00 3.84 31717.00
0 0.00 466.00 4.10 31720.00
1 0.73 465.00 3.84 31723.00
0 0.00 465.00 3.84 31725.00
0 0.00 465.00 3.84 31728.00
0 0.00 465.00 3.84 31730.00
0 0.00 465.00 3.84 31733.00
0 0.00 466.00 4.10 31736.00
1 0.73 467.00 4.35 31738.00
1 0.73 464.00 3.58 31741.00
1 0.73 465.00 3.84 31744.00
0 0.00 464.00 3.58 31746.00
1 0.73 465.00 3.84 31749.00
2 1.45 465.00 3.84 31752.00
1 0.73 464.00 3.58 31754.00
0 0.00 464.00 3.58 31757.00
1 0.73 464.00 3.58 31760.00
2 1.45 464.00 3.58 31763.00
1 0.73 464.00 3.58 31765.00
0 0.00 463.00 3.33 31768.00
1 0.73 462.00 3.07 31770.00
1 0.73 462.00 3.07 31773.00
2 1.45 462.00 3.07 31776.00
0 0.00 461.00 2.82 31779.00
1 0.73 461.00 2.82 31781.00
1 0.73 460.00 2.56 31784.00
0 0.00 460.00 2.56 31786.00
0 0.00 460.00 2.56 31789.00
1 0.73 460.00 2.56 31792.00
3 2.18 460.00 2.56 31795.00
2 1.45 460.00 2.56 31798.00
3 2.18 459.00 2.30 31801.00
2 1.45 459.00 2.30 31804.00
3 2.18 458.00 2.05 31807.00
2 1.45 457.00 1.79 31810.00
3 2.18 457.00 1.79 31813.00
2 1.45 457.00 1.79 31816.00
3 2.18 457.00 1.79 31819.00
2 1.45 456.00 1.53 31822.00
2 1.45 455.00 1.28 31825.00
2 1.45 455.00 1.28 31828.00
2 1.45 456.00 1.53 31831.00
1 0.73 455.00 1.28 31834.00
2 1.45 455.00 1.28 31837.00
1 0.73 454.00 1.02 31839.00
1 0.73 454.00 1.02 31842.00
1 0.73 454.00 1.02 31844.00
1 0.73 453.00 0.76 31847.00
0 0.00 453.00 0.76 31850.00
0 0.00 454.00 1.02 31852.00
1 0.73 453.00 0.76 31855.00
1 0.73 454.00 1.02 31857.00
1 0.73 453.00 0.76 31860.00
1 0.73 453.00 0.76 31863.00
2 1.45 454.00 1.02 31866.00
2 1.45 454.00 1.02 31869.00
2 1.45 453.00 0.76 31872.00
2 1.45 454.00 1.02 31875.00
0 0.00 453.00 0.76 31877.00
1 0.73 454.00 1.02 31880.00
2 1.45 454.00 1.02 31883.00
1 0.73 454.00 1.02 31885.00
0 0.00 454.00 1.02 31888.00
1 0.73 454.00 1.02 31891.00
2 1.45 453.00 0.76 31894.00
1 0.73 451.00 0.25 31896.00
2 1.45 453.00 0.76 31899.00
1 0.73 453.00 0.76 31902.00
1 0.73 452.00 0.51 31905.00
1 0.73 454.00 1.02 31907.00
0 0.00 453.00 0.76 31910.00
1 0.73 454.00 1.02 31913.00
1 0.73 453.00 0.76 31915.00
2 1.45 453.00 0.76 31918.00
1 0.73 453.00 0.76 31921.00
0 0.00 453.00 0.76 31923.00
1 0.73 453.00 0.76 31926.00
1 0.73 454.00 1.02 31929.00
2 1.45 453.00 0.76 31932.00
1 0.73 453.00 0.76 31934.00
1 0.73 454.00 1.02 31937.00
4 2.90 453.00 0.76 31940.00
0 0.00 453.00 0.76 31942.00
1 0.73 453.00 0.76 31945.00
0 0.00 453.00 0.76 31948.00
2 1.45 454.00 1.02 31951.00
0 0.00 453.00 0.76 31953.00
0 0.00 452.00 0.51 31956.00
1 0.73 451.00 0.25 31958.00
1 0.73 453.00 0.76 31961.00
1 0.73 453.00 0.76 31964.00
1 0.73 453.00 0.76 31966.00
1 0.73 452.00 0.51 31969.00
1 0.73 453.00 0.76 31971.00
1 0.73 452.00 0.51 31974.00
0 0.00 452.00 0.51 31977.00
0 0.00 453.00 0.76 31979.00
0 0.00 453.00 0.76 31982.00
2 1.45 453.00 0.76 31985.00
0 0.00 453.00 0.76 31987.00
1 0.73 452.00 0.51 31990.00
0 0.00 452.00 0.51 31992.00
0 0.00 452.00 0.51 31995.00
1 0.73 453.00 0.76 31998.00
0 0.00 453.00 0.76 32000.00
0 0.00 452.00 0.51 32003.00
1 0.73 453.00 0.76 32005.00
0 0.00 453.00 0.76 32008.00
0 0.00 452.00 0.51 32011.00
0 0.00 452.00 0.51 32013.00
0 0.00 453.00 0.76 32016.00
1 0.73 453.00 0.76 32018.00
1 0.73 452.00 0.51 32021.00
0 0.00 452.00 0.51 32024.00
0 0.00 452.00 0.51 32026.00
1 0.73 451.00 0.25 32029.00
1 0.73 452.00 0.51 32032.00
1 0.73 452.00 0.51 32034.00
1 0.73 452.00 0.51 32037.00
1 0.73 453.00 0.76 32039.00
1 0.73 454.00 1.02 32042.00
1 0.73 454.00 1.02 32045.00
1 0.73 453.00 0.76 32047.00
1 0.73 453.00 0.76 32050.00
1 0.73 452.00 0.51 32052.00
0 0.00 454.00 1.02 32055.00
1 0.73 452.00 0.51 32058.00
1 0.73 453.00 0.76 32060.00
1 0.73 453.00 0.76 32063.00
0 0.00 453.00 0.76 32065.00
0 0.00 452.00 0.51 32068.00
1 0.73 454.00 1.02 32071.00
0 0.00 453.00 0.76 32073.00
1 0.73 453.00 0.76 32076.00
0 0.00 453.00 0.76 32078.00
0 0.00 453.00 0.76 32081.00
1 0.73 453.00 0.76 32084.00
0 0.00 453.00 0.76 32086.00
1 0.73 453.00 0.76 32089.00
1 0.73 453.00 0.76 32091.00
1 0.73 453.00 0.76 32094.00
1 0.73 451.00 0.25 32097.00
1 0.73 452.00 0.51 32099.00
0 0.00 453.00 0.76 32102.00
1 0.73 453.00 0.76 32104.00
1 0.73 453.00 0.76 32107.00
1 0.73 453.00 0.76 32110.00
0 0.00 454.00 1.02 32112.00
0 0.00 452.00 0.51 32115.00
1 0.73 452.00 0.51 32117.00
1 0.73 452.00 0.51 32120.00
0 0.00 452.00 0.51 32123.00
1 0.73 453.00 0.76 32125.00
1 0.73 453.00 0.76 32128.00
1 0.73 453.00 0.76 32131.00
0 0.00 452.00 0.51 32133.00
1 0.73 452.00 0.51 32136.00
0 0.00 452.00 0.51 32138.00
1 0.73 452.00 0.51 32141.00
2 1.45 453.00 0.76 32144.00
1 0.73 452.00 0.51 32147.00
2 1.45 452.00 0.51 32150.00
1 0.73 454.00 1.02 32152.00
2 1.45 452.00 0.51 32155.00
0 0.00 452.00 0.51 32158.00
2 1.45 451.00 0.25 32161.00
2 1.45 451.00 0.25 32164.00
0 0.00 453.00 0.76 32166.00
0 0.00 453.00 0.76 32169.00
0 0.00 451.00 0.25 32172.00
1 0.73 452.00 0.51 32174.00
1 0.73 452.00 0.51 32177.00
1 0.73 453.00 0.76 32179.00
0 0.00 453.00 0.76 32182.00
1 0.73 451.00 0.25 32185.00
1 0.73 453.00 0.76 32187.00
2 1.45 453.00 0.76 32190.00
1 0.73 453.00 0.76 32193.00
1 0.73 453.00 0.76 32195.00
1 0.73 453.00 0.76 32198.00
2 1.45 452.00 0.51 32201.00
0 0.00 453.00 0.76 32204.00
1 0.73 453.00 0.76 32206.00
0 0.00 452.00 0.51 32209.00
0 0.00 452.00 0.51 32212.00
0 0.00 453.00 0.76 32214.00
0 0.00 452.00 0.51 32217.00
0 0.00 454.00 1.02 32219.00
1 0.73 453.00 0.76 32222.00
0 0.00 453.00 0.76 32225.00
0 0.00 452.00 0.51 32227.00
0 0.00 453.00 0.76 32230.00
1 0.73 453.00 0.76 32232.00
2 1.45 452.00 0.51 32235.00
1 0.73 453.00 0.76 32238.00
1 0.73 452.00 0.51 32241.00
1 0.73 453.00 0.76 32243.00
1 0.73 453.00 0.76 32246.00
0 0.00 452.00 0.51 32248.00
1 0.73 453.00 0.76 32251.00
0 0.00 453.00 0.76 32254.00
0 0.00 453.00 0.76 32256.00
1 0.73 453.00 0.76 32259.00
0 0.00 453.00 0.76 32261.00
0 0.00 453.00 0.76 32264.00
1 0.73 453.00 0.76 32267.00
1 0.73 453.00 0.76 32269.00
1 0.73 452.00 0.51 32272.00
0 0.00 452.00 0.51 32274.00
0 0.00 453.00 0.76 32277.00
1 0.73 452.00 0.51 32280.00
0 0.00 453.00 0.76 32282.00
2 1.45 452.00 0.51 32285.00
0 0.00 454.00 1.02 32288.00
1 0.73 452.00 0.51 32290.00
0 0.00 453.00 0.76 32293.00
0 0.00 453.00 0.76 32296.00
0 0.00 453.00 0.76 32298.00
0 0.00 452.00 0.51 32301.00
1 0.73 452.00 0.51 32303.00
0 0.00 452.00 0.51 32306.00
0 0.00 453.00 0.76 32309.00
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

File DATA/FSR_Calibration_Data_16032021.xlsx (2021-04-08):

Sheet: Curve Fitting
FSR Reading | Weight reading (g)
0 | 0 |  | Acceptable readings from 200g to 900g
170 | 60
260 | 250
410 | 300
600 | 350
700 | 400
760 | 450
710 | 500
0 | 0
150 | 130
200 | 200
300 | 250
420 | 300
530 | 400
650 | 500
770 | 600
950 | 700
970 | 800
960 | 900
900 | 1000
1000 | 1100
1023 | 1200
0 | 0
300 | 100
200 | 150
250 | 200
500 | 300
550 | 400
600 | 500
650 | 600
870 | 700
880 | 800
950 | 900
890 | 1000
980 | 1100
950 | 1200
900 | 1300 | Weigh reading (g) | FSR1 | FSR2 | FSR3
 |  | 130 | 150 | 200 | 150
 |  | 200 | 200 | 250 | 200
 |  | 300 | 420 | 500 | 500
0 | 0 | 400 | 530 | 550 | 590
150 | 110 | 500 | 650 | 600 | 670
200 | 200 | 600 | 770 | 650 | 800
500 | 300 | 700 | 950 | 870 | 750
590 | 400 | 800 | 970 | 880 | 850
670 | 500 | 900 | 960 | 950 | 1000
800 | 600
750 | 700
850 | 800
1000 | 900
930 | 1000
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

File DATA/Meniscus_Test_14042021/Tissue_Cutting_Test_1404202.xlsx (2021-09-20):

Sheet: Overview
 | Tissue Cutting test 14042021
 | Each test includes a series of at least 10 cuts.
Test # | Tests performed | Comments | Time stamp
1 | Blank Slow | Blank cut in sheet of print paper. Tape mountet over FSR to distribute pressure. | 1758
2 | Blank Fast | Blank cut in sheet of print paper. Tape mountet over FSR to distribute pressure. | 1759
3 | Meniscus Slow | Slow and controlled cut in meniscus. Tape mounted over FSR to distribute pressure. | 1804
4 | Meniscus Slow | Slow and controlled cut in meniscus. Tape mounted over FSR to distribute pressure. | 1811
5 | Meniscus Fast | Faster meniscus cut. Tape mounted over FSR to distribute pressure. | 1807
6 | Meniscus Fast | Faster meniscus cut. Tape mounted over FSR to distribute pressure. | 1814
7 | Blank Slow | Blank cut in sheet of print paper. Tape removed. | 1819
8 | Blank Fast | Blank cut in sheet of print paper. Tape removed0 | 1821
9 | Meniscus Slow | Slow and controlled cut in meniscus. Tape removed. | 1824
10 | Meniscus Slow | Slow and controlled cut in meniscus. Tape removed. Meniscus removed from knee. | 1839
11 | Meniscus Fast | Faster meniscus cuts. Tape removed. | 1826
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

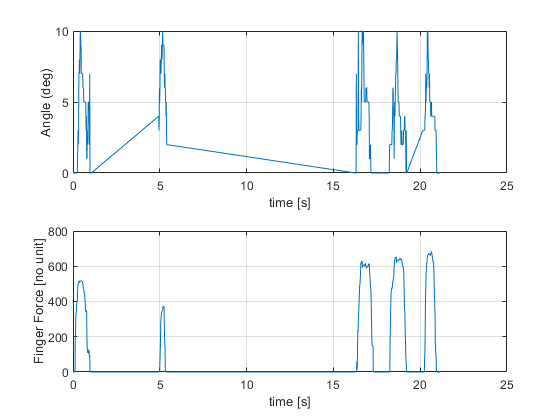
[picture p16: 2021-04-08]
MATLAB/html/Pilot_testing_finger_steak_17022021_01.png

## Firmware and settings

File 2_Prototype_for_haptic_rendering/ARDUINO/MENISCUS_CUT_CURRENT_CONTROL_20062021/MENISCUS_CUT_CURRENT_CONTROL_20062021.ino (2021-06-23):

/**
 * Virtual wall rendering with:
 * Torque control example using voltage control loop.
 * 

 */
#include <SimpleFOC.h>
#include <math.h>

// BLDC motor & driver instance
BLDCMotor motor = BLDCMotor(7);
BLDCDriver3PWM driver = BLDCDriver3PWM(9, 5, 6, 8);

// encoder instance
Encoder encoder = Encoder(3, 2, 2048);


// Interrupt routine intialisation
// channel A and B callbacks
void doA(){encoder.handleA();}
void doB(){encoder.handleB();}

// current sensor
InlineCurrentSense current_sense = InlineCurrentSense(0.01, 50.0, A0, A2);

// current set point variable
float target_current = 0.0;
// instantiate the commander
Commander command = Commander(Serial);
void doTarget(char* cmd) { command.scalar(&target_current, cmd); }


// Variables for cutting curve and the four regions
double xh = 0; //handle position [rad]
double vh = 0; //Handle velocity [rad/s]

double xOpen = 0; // Variable for storing the opening position. Used for computing hysteresis.
bool checkpoint = false;
double force = 0; // Target force [N]

double xIntercept = 4.8*(M_PI/180);   // position of interception point [rad]
double kElastic = 182;                  // stiffness of elastic region [N/rad] (3.17 N/deg)

double xYield = 7*(M_PI/180);         // Position of yield point [rad]
double fYield = 0;                    // Yield Force [N]
double kPlastic = 22;                  // Stiffness of plastic region [N/rad]

double xBottomOut = 11*(M_PI/180);   // Position of bottom out point [rad]
double fBottomOut = 0;                // Bottom out force [N]
double kBottomOut = 300;               // Stiffness of bottom out region [N/rad]

double xOpening = 11*(M_PI/180);       // Position of opening point [rad]
double fOpening = 0;                  // Opening force [N]
double kOpening = 100;                  // Stiffness of opening region [N/rad]

// For sampling time stamps
double currentMillis = 0;

//  Constant for converting from force to current
double forceC = 0.01; // I.e. 10N becomes 0.1A


void setup() { 
  
  // initialize encoder sensor hardware
  encoder.init();
  encoder.enableInterrupts(doA, doB); 
  // link the motor to the sensor
  motor.linkSensor(&encoder);

  // driver config
  // power supply voltage [V]
  driver.voltage_power_supply = 12;
  driver.init();
  // link driver
  motor.linkDriver(&driver);


  // current sense init hardware
  current_sense.init();
  // link the current sense to the motor
  motor.linkCurrentSense(&current_sense);

  // set torque mode:
  // TorqueControlType::dc_current 
  // TorqueControlType::voltage
  // TorqueControlType::foc_current
  motor.torque_controller = TorqueControlType::dc_current; 
  // set motion control loop to be used
  motor.controller = MotionControlType::torque;

  // foc current control parameters (Arduino UNO/Mega)
  motor.PID_current_q.P = 5;
  motor.PID_current_q.I= 300;
  motor.LPF_current_q.Tf = 0.01; 

  // use monitoring with serial 
  Serial.begin(115200);
  // comment out if not needed
  motor.useMonitoring(Serial);

  // initialize motor
  motor.init();
  // align sensor and start FOC
  motor.initFOC();

  Serial.println(F("Motor ready."));
  _delay(1000);
}

void loop() {

  // main FOC algorithm function
  // the faster you run this function the better
  // Arduino UNO loop  ~1kHz
  // Bluepill loop ~10kHz 
  motor.loopFOC();

  xh = encoder.getAngle();
  double xhDeg = (xh/M_PI)*180;
  vh = encoder.getVelocity();


    // Implementing the four different regions 

    //Linear-elastic region
    if((xh > xIntercept) && (xh < xYield) && (checkpoint == false)) {
    
        force = -kElastic*(xh-xIntercept);     
        fYield = force;
        xOpen = xh;

    // Plastic/cutting region
    }else if((xh >= xYield) && (xh < xBottomOut) && (checkpoint == false)) {

        force = fYield + kPlastic*(xh-xYield);
        fBottomOut = force;
        xOpen = xh;

    // Bottom-out region (this should be stiffer)
    }else if((xh >= xBottomOut) && (checkpoint == false)){

        force = fBottomOut - kBottomOut*(xh-xBottomOut);
        fOpening = force;
        xOpen = xh;
        checkpoint = true;

    }else if((checkpoint == true)){

        force = fBottomOut - kBottomOut*(xh-xBottomOut);
   
    }else{
      force = 0;
    }

  if((xh < xIntercept) && (checkpoint == true)){
    checkpoint = false;
  }


  target_current = force*forceC;

  // Finally a capping to prevent overloading the motor
  if(target_current < -0.3){
      target_current = -0.3;
  }else if(target_current > 0.3){
    target_current = 0.3;
  } 


 //******************
    
  Serial.print(target_current);
  Serial.print("\t");
  Serial.print(xhDeg);
  Serial.print("\t");
  Serial.print(vh);
  Serial.print("\t");
  currentMillis = millis();
  Serial.print(currentMillis);
  Serial.println("\t");
  
  // Motion control function
  // velocity, position or voltage (defined in motor.controller)
  // this function can be run at much lower frequency than loopFOC() function
  // You can also use motor.move() and set the motor.target in the code
  motor.move(target_current);

}

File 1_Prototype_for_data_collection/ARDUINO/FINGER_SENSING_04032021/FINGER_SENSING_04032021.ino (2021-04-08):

// Code for reading finger force data using FSR-sensor, and corresponding angular position using potmeter, for arthroscopic grasper.
// By Øystein Bjelland, CPS-lab, Department of ICT and Natural Sciences, NTNU

// Code based on learn.adafruit.com/force-sensitive-resistor-fsr/using-an-fsr 

// --------------------------------

// Define FSR-variables

int fsrPin = 0;    // FSR and 10kohm pulldown are connected to a0.
int fsrReading;   // The analog reading from the FSR resistor divider.
int fsrVoltage;   // The analog reading converted to voltage.
double fsrResistance;  //  The voltage converted to resistance, can be very big so make "long".
double fsrConductance; //
double fsrForce;    // Resistance converted to force


// Define potensiometer variables
int potPin = 1;    // Read potmeter from a1
double potVal = 0.00;   
double maxpotVal = 0.00;
double minpotVal = 0.00;
double angle = 0.00;

// Time stamp in milliseconds
double currentMillis = 0;


// --------------------------

void setup() {
  // Begin serial communication at baud rate of 9600;
  Serial.begin(9600);

  delay(5000);

  Serial.println("Please move the lever to the outermost position and hold for 5 seconds");
      while (millis() < 10000) {
        minpotVal = analogRead(potPin);
      }

  delay(5000);

  Serial.println("Please move the lever to the innermost position and hold for 5 seconds");
      while (millis() < 20000) {
        maxpotVal = analogRead(potPin);
      }

  Serial.println("Potentiometer calibration completed");


  delay(5000);
  
  Serial.println("FSR reading, FSR Force [N], angle [deg], time [ms]");  
}



// -------------------------------



void loop() {
 
  // FSR-section
  fsrReading = analogRead(fsrPin);    //Read analog value from fsrPin
  fsrVoltage = map(fsrReading, 0, 1023, 0, 5000); //analog voltage reading ranges from 0 to 1023 which maps to 0V to 5v (=5000mV)

  if (fsrVoltage == 0) {
      // No pressure!
  } else {
      // The voltage = Vcc * R / (R + FSR), where R = 10kOhm and Vcc = 5V
      // So FSR = ((Vcc - V)*R / V
      fsrResistance = 5000 - fsrVoltage;  // milliVolts --> 5V = 5000mV
      fsrResistance *= 10000;           // 10kOhm resistor. (equals fsrResistance = fsrResistance * 10 000)
      fsrResistance /= fsrVoltage;      // fsrResistance = fsrResistance / fsrVoltage

      fsrConductance = 1000000;   // measure in microMhos G = 1/R
      fsrConductance /= fsrResistance;

      // Use two FSR guide graphs to approximate the force
      if (fsrConductance <= 1000) {
        fsrForce = fsrConductance / 80; // fsrForce in Newtons
      } else {
        fsrForce = fsrConductance - 1000;
        fsrForce /= 30;   //fsrForce in Newtons
      }
  }

  // Potmeter section
  potVal = analogRead(potPin);
  angle = map(potVal, minpotVal, maxpotVal, 0.00, 1000); // angle in degrees
  double anglePres = angle/100;


  // Print reading to serial monitor
  Serial.print(fsrReading);
  Serial.print("\t");
  Serial.print("");

  Serial.print(fsrForce);
  Serial.print("\t");
  Serial.print("");

  //Serial.print(potVal);
  Serial.print(anglePres);
  Serial.print("\t");
  Serial.print("");

  currentMillis = millis();
  Serial.print(currentMillis);
  Serial.print("\t");
  Serial.println("");

   delay(50); // Delay 5ms. But we dont really want any delay.

}

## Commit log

2021-09-15 Recent iterations and rendering strategies
    [Force-deflection_identification.xlsx]
2021-09-15 Reorganizing folder structure
    [26012021_Data_filtrert.xlsx, 4mm_SHAFT.prt, 5mm_ADAPTER.prt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]
2021-09-20 Added experimental Data to folder structure
    [26012021_Data_filtrert.xlsx, Tissue_Cutting_Test_1404202.xlsx]
